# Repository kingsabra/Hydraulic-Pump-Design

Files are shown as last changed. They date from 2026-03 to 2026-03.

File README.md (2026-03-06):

# Hydraulic Pump Design — Bilge Pump

Mechanical design and assembly package for a **hand-crank / mechatronic bilge pump** (piston pump). Created for **U.S. Coast Guard Academy — Introduction to Mechanical Design (IMED), Spring 2022**, Team 4.

The pump can be built in two configurations: **manual crank drive** or **motorized drive** controlled by an Arduino and a water-level sensor.

---

## Repository structure

| Folder | Contents |
|---|---|
| **`cad/`** | All SolidWorks files: main assembly, pump parts, fasteners, and drawings. Open `cad/Assem1.SLDASM` in SolidWorks to view the full assembly. |
| **`docs/`** | Reports (assembly instructions, BOM, drawing exports) in PDF and DOCX. |
| **`media/`** | Renders and animations (e.g. mechanism animation). |
| **`misc/`** | Other artifacts (e.g. SolidWorks add-in logs); safe to ignore for normal use. |

---

## What’s in each folder

### `cad/`
- **`Assem1.SLDASM`** — Main pump assembly.
- **Parts (`.SLDPRT`)** — Pump body, piston, connecting rod, axle, crank disk, crank handle, handle, support arm, piston screw, quick-disconnect coupling (male).
- **`screws/`** — Fastener and fitting library (set screws, bolts, brass fitting, etc.) used in the assembly.
- **`IMED_MS_001.SLDDRW`** — Multi-sheet drawing (BOM and part/detail views).
- **`CGA B Landscape.slddrt`** — Drawing template (title block, border).

### `docs/`
- **Assembly Report Team 4** (`.pdf`, `.docx`) — Full assembly process: pump body, handle, and mechatronics wiring. Primary reference for building the pump.
- **assembly report - Moustafa Mahmoud Sabra** (`.pdf`, `.docx`) — Separate OIR/interview report (not pump assembly steps).
- **`IMED_MS_drawings.PDF`** — Exported drawing set (BOM, dimensions, tolerances).

### `media/`
- **`Animation1.mp4`** — Short animation of the pump mechanism.

### `misc/`
- **`console.log`** — SolidWorks Marketplace add-in log; not part of the design. You can add `misc/console.log` to `.gitignore` if you don’t want it in the repo.

---

## Main parts (from BOM)

Pump body, support arm, axle, crank disk, crank handle, handle, connecting rod, piston, piston screw, quick-disconnect coupling, plus standard hardware (set screws, bolts, NPT barbed fitting, ball bearings) as listed in the assembly report and `IMED_MS_drawings.PDF`.

---

## How to use this repo

1. **View the assembly** — Open **SolidWorks** and open `cad/Assem1.SLDASM`. Keep all files under `cad/` (and `cad/screws/`) in place so references don’t break.
2. **Build the pump** — Follow **`docs/Assembly Report Team 4.pdf`** for step-by-step assembly (manual and mechatronics).
3. **Drawings and BOM** — Use **`docs/IMED_MS_drawings.PDF`** for dimensions and part list, or open `cad/IMED_MS_001.SLDDRW` in SolidWorks.

---

## Note on Arduino / firmware

The assembly report describes an **Arduino-based circuit** (C code in Arduino IDE) for motor control and water-level sensing. That **firmware is not included** in this repository; this repo contains only CAD and documentation. If you have the original sketch, you can add it in a folder such as `firmware/` and reference it in this README.

---

## License and use

SolidWorks files are marked as **Educational Product**. Use according to your institution’s and SolidWorks’ terms. Reports and drawings are from the referenced course and authors.

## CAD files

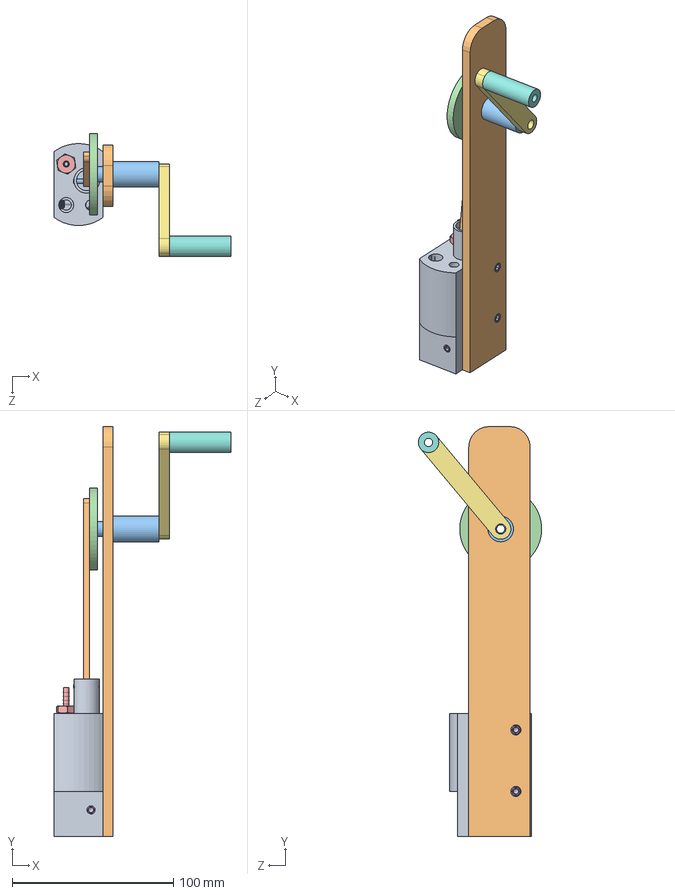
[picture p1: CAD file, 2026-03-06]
cad/Assem1.SLDASM
109.5 x 254.0 x 76.4 mm
Pump Body
Support Arm
Pump Axie
Pump Crank Disk
5454K650_MINIATURE BRASS FITTING
92158A417_Super-Corrosion-Resistant Flat-Tip Set Screws x 6
Pump Crank Handle
Pump Handle
Pump Piston
Pump Connecting Rod
piston screw

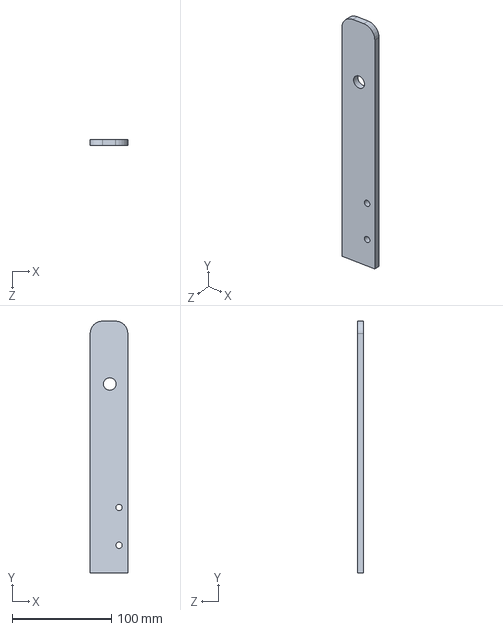
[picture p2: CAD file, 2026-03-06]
cad/Support Arm.SLDPRT
38.1 x 254.0 x 6.35 mm

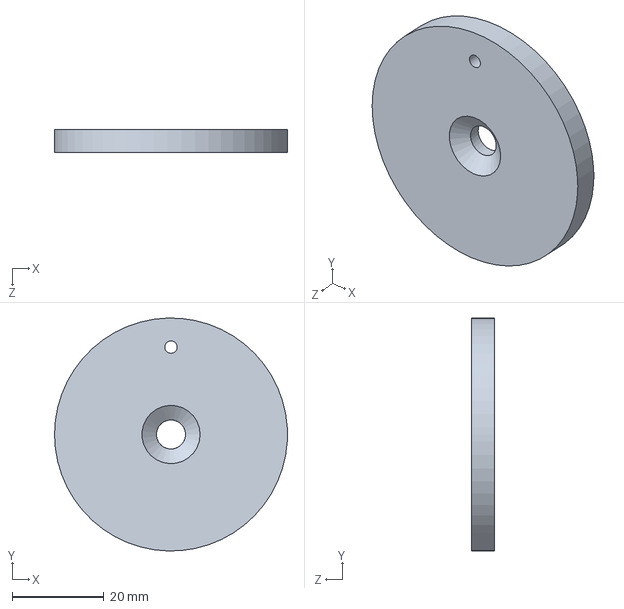
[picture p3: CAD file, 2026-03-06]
cad/Pump Crank Disk.SLDPRT
50.8 x 50.8 x 5.08 mm

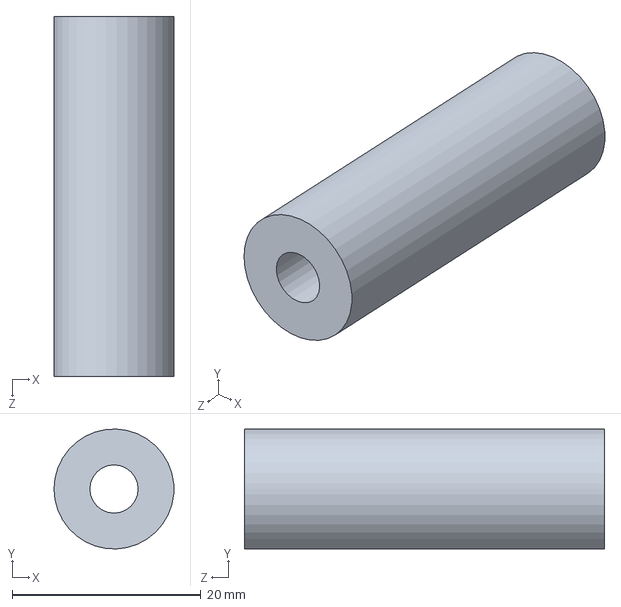
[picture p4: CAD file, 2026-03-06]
cad/Pump Handle.SLDPRT
12.7 x 12.7 x 38.1 mm

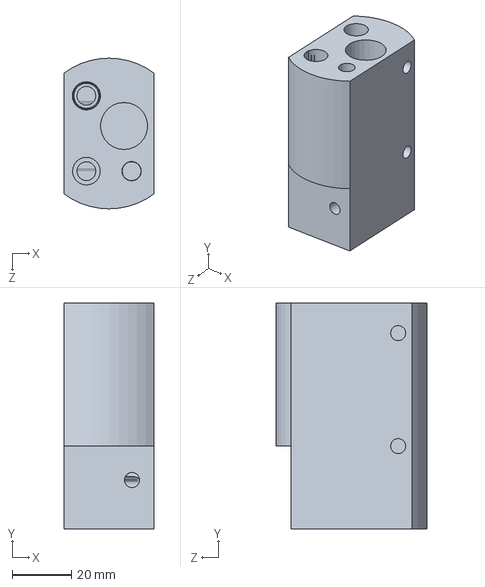
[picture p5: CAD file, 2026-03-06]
cad/Pump Body.SLDPRT
30.2 x 76.2 x 50.8 mm

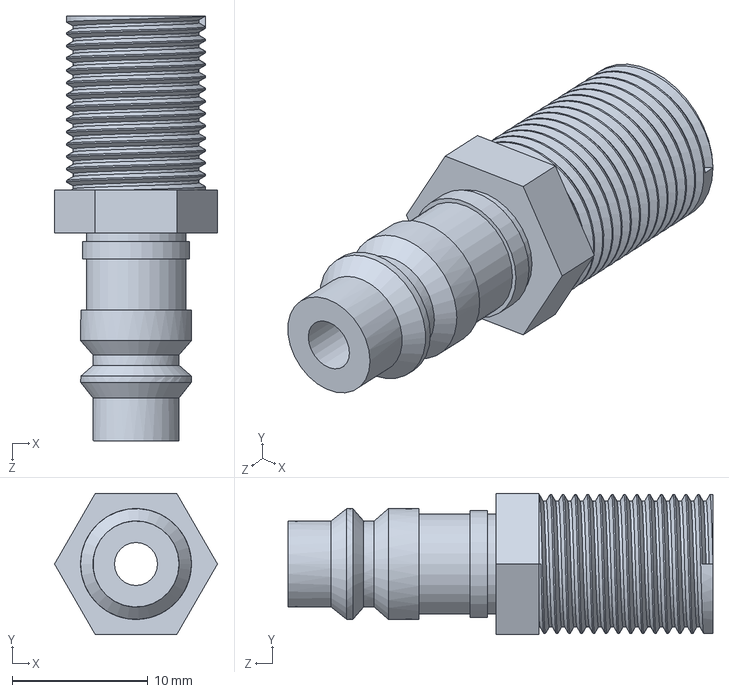
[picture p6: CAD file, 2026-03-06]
cad/quick disconnect coupling male.SLDPRT
12.0 x 10.4 x 31.4 mm

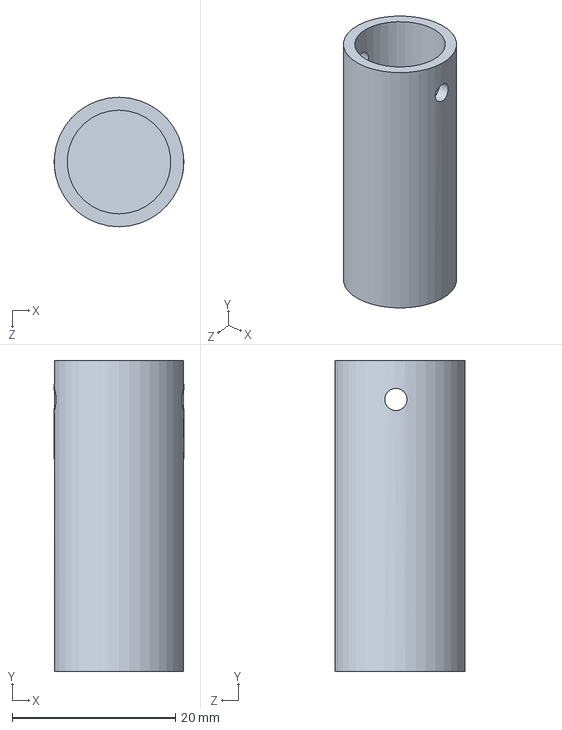
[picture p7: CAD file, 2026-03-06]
cad/Pump Piston.SLDPRT
15.9 x 38.1 x 15.9 mm

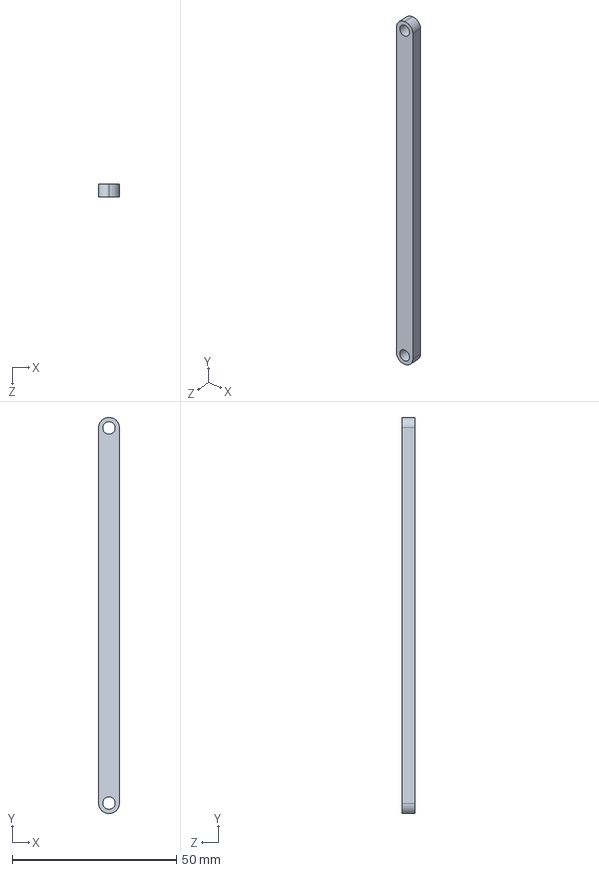
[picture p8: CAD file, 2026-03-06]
cad/Pump Connecting Rod.SLDPRT
6.35 x 120.7 x 3.81 mm

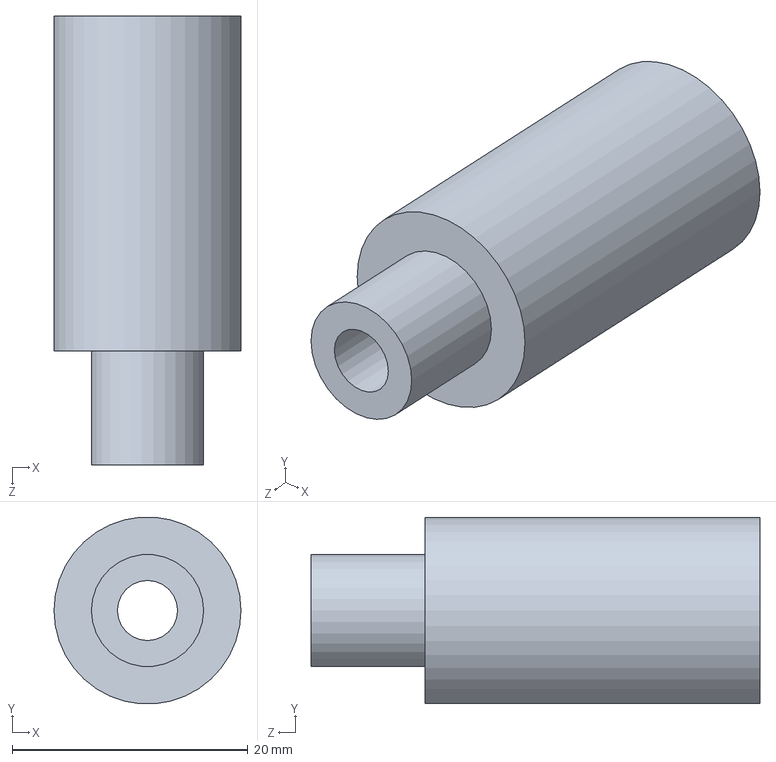
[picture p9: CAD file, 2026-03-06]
cad/Pump Axie.SLDPRT
15.9 x 15.8 x 38.1 mm

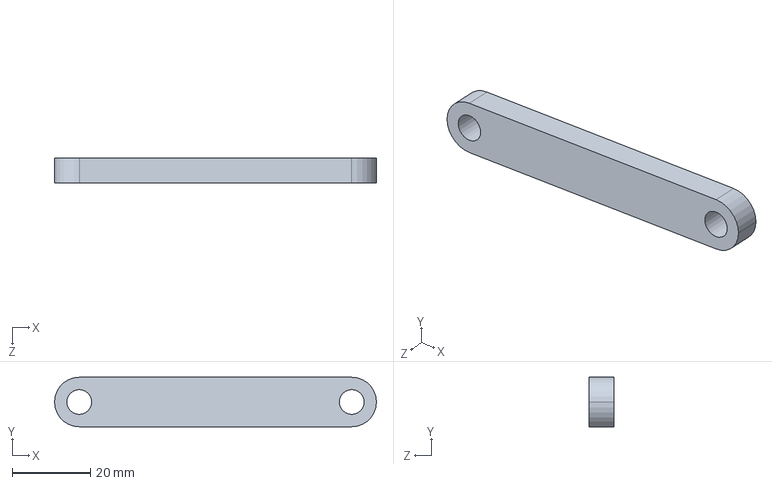
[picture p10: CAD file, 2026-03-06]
cad/Pump Crank Handle.SLDPRT
82.5 x 12.7 x 6.35 mm

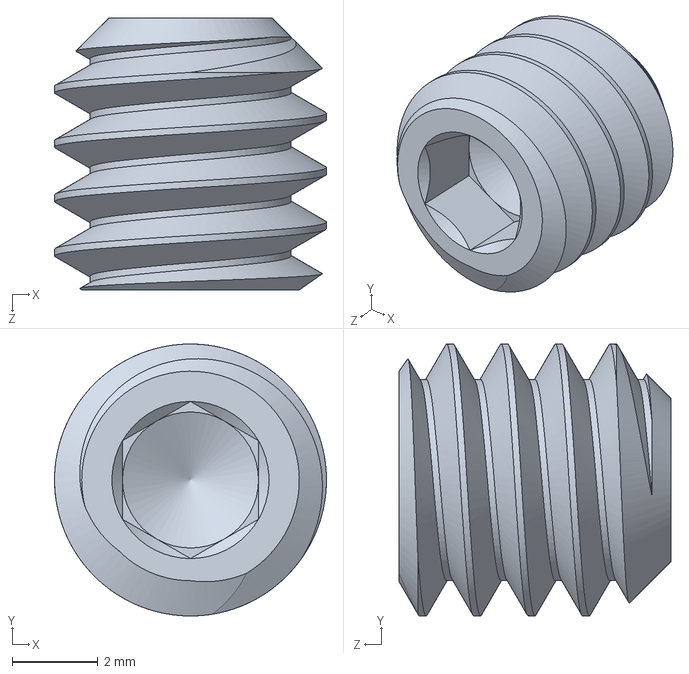
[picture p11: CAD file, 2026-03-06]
cad/screws/92158A417_Super-Corrosion-Resistant Flat-Tip Set Screws.SLDPRT
6.35 x 6.35 x 6.35 mm

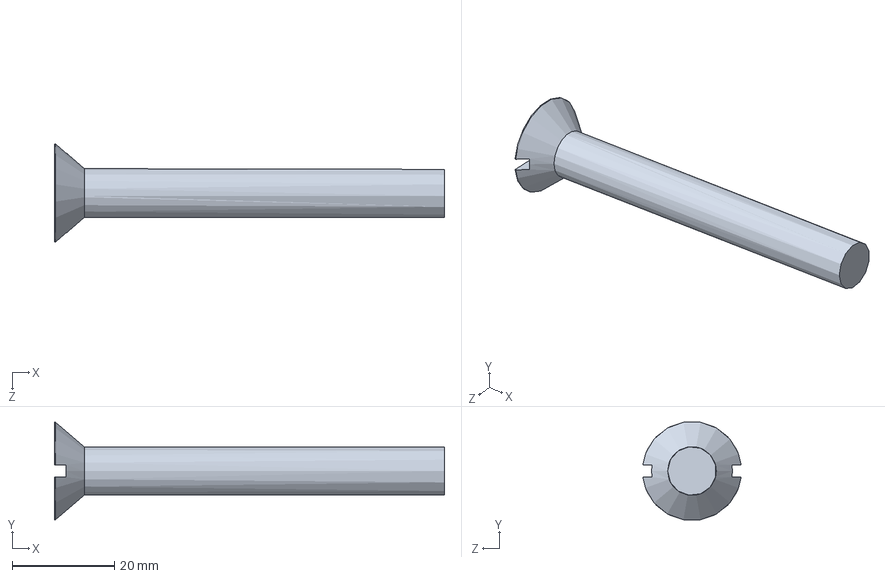
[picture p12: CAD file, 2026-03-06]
cad/screws/CSBOLT 0.2500-20x0.75x0.75-S-N.sldprt
76.2 x 19.1 x 19.2 mm

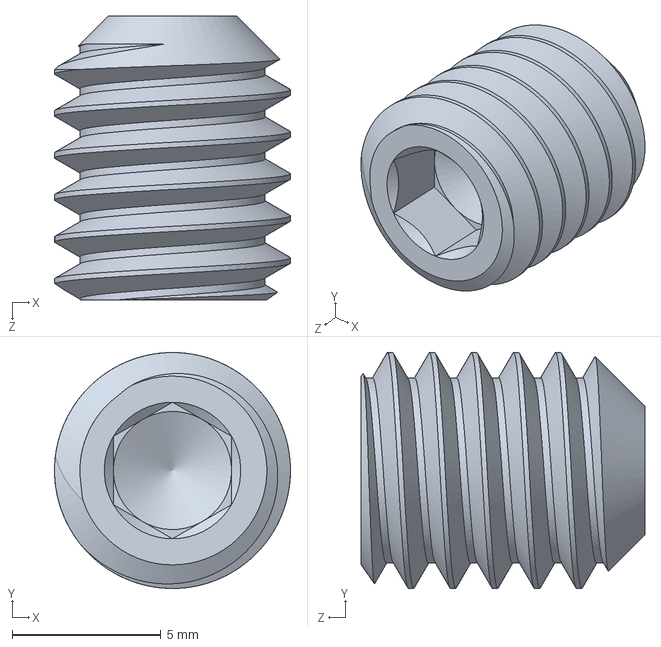
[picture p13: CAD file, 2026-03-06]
cad/screws/92311A576_18-8 Stainless Steel Cup-Point Set Screw.SLDPRT
7.92 x 7.92 x 9.52 mm

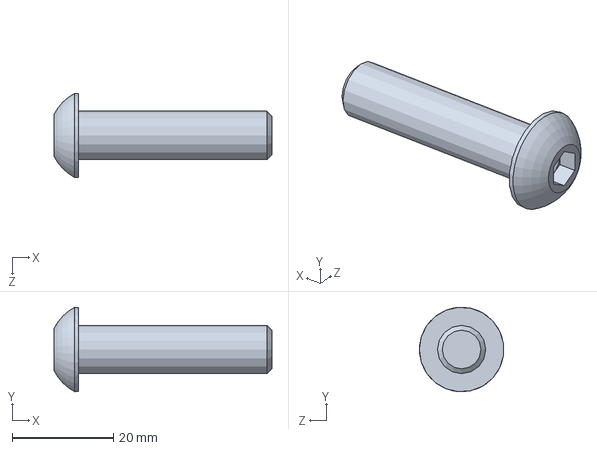
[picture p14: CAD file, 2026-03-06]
cad/screws/SBHCSCREW 0.138-32x0.375-HX-N.sldprt
43.0 x 16.7 x 16.6 mm

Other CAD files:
cad/piston screw.SLDPRT
cad/screws/5454K650_MINIATURE BRASS FITTING.SLDPRT
cad/screws/SBHCSCREW 0.125-40x0.375-HX-N.sldprt
cad/screws/CSBOLT 0.2500-20x0.5x0.5-S-N.sldprt
cad/IMED_MS_001.SLDDRW
cad/screws/92311A937_18-8 Stainless Steel Cup-Point Set Screw.SLDPRT
cad/screws/CSBOLT 0.2500-20x0.75x0.75-S-C.sldprt
cad/screws/HBOLT 0.2500-20x0.5x0.5-N.sldprt

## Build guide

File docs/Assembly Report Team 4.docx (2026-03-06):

Report No: 4001

U.S Coast Guard Academy

Introduction to Mechanical Design (1208)

2022

Team 4: Bilge Pump

Bilge Pump

Author: Moustafa Mahmoud Sabra ________________________

Checked: 3/c Kevin Hall ________________________

Issue Date: 04/27/2022

Electronic Folder: IMED Spring 2022\Documents\General\Lab Material

# Abstract

Assembling the bilge pump requires minimal tools or experience and can be completed by splitting the pump into a few fundamental pieces. The assembly processes can be broken into the pump body assembly, the handle assembly, the mechatronics circuit assembly, and eventually the final product assembly. The exact steps are detailed in this report.

# Acknowledgment

It is essential to acknowledge that the completion of the prototype would not have been possible without the supervision of CDR Ryan Angelo and Dr. Richard Freeman. In addition, a special thanks should be issued to the managing staff of the United States Coast Guard Academy Power Lab for their contributions toward the fabrication and assembly of the pump body parts and final product.

# Chapter 1: Introduction

The parts manufactured using machines in the Power Lab include the pump body, support arm, axle, connecting rod, crank arm, crank disc, piston, and handle.

Additional parts were used to enable the mechanics and connections between the main parts mentioned previously, containing the NPT barbed fitting, ball bearings, and set screws with appropriate sizes that match the design parameters.

An Arduino-based circuit was constructed to control the rotation of the pump motor and piston. An EGLEGOO Mega R3, Arduino Motor Shield, motor driver, breadboard, power supply, jumpers, and water level sensor were used to construct the monitoring circuit.

The final prototype comes with two configurations, either a manual-based drive or a mechatronic-based drive. The manual drive relies on the user exerting force manually to turn the crank disk, while the mechatronic-based version utilizes a DC motor for rotating the crank disk.

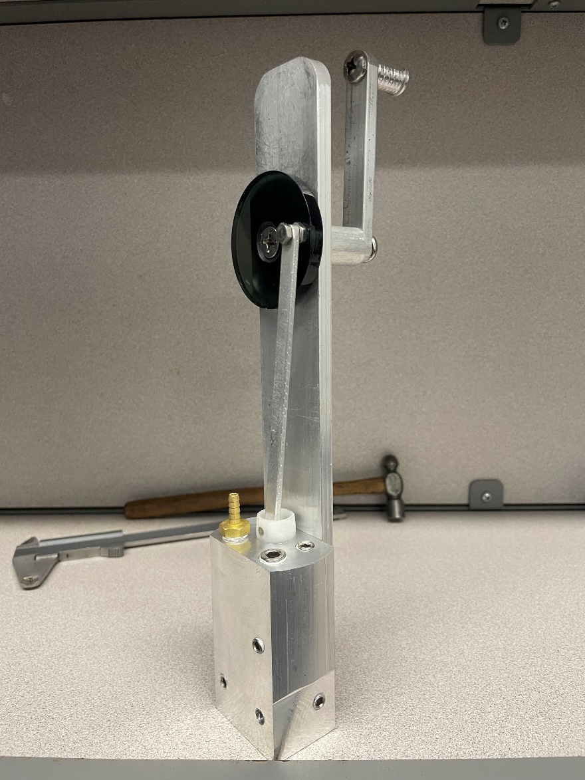
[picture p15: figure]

Support Arm

1/8 NPT Barbed Fitting

5/16 inch Set Screw

7/16 inch Set Screw

Piston

1/4 inch Set Screw

1/4 inch Set Screw

Axel

Crank Rod

Handle

Pump Body

Connecting Rod

Crank Disc

Figure 1 Assembled pump with hand crank

The project’s parts are labeled in Figure 1 above and the final prototype is shown in Figure 2.

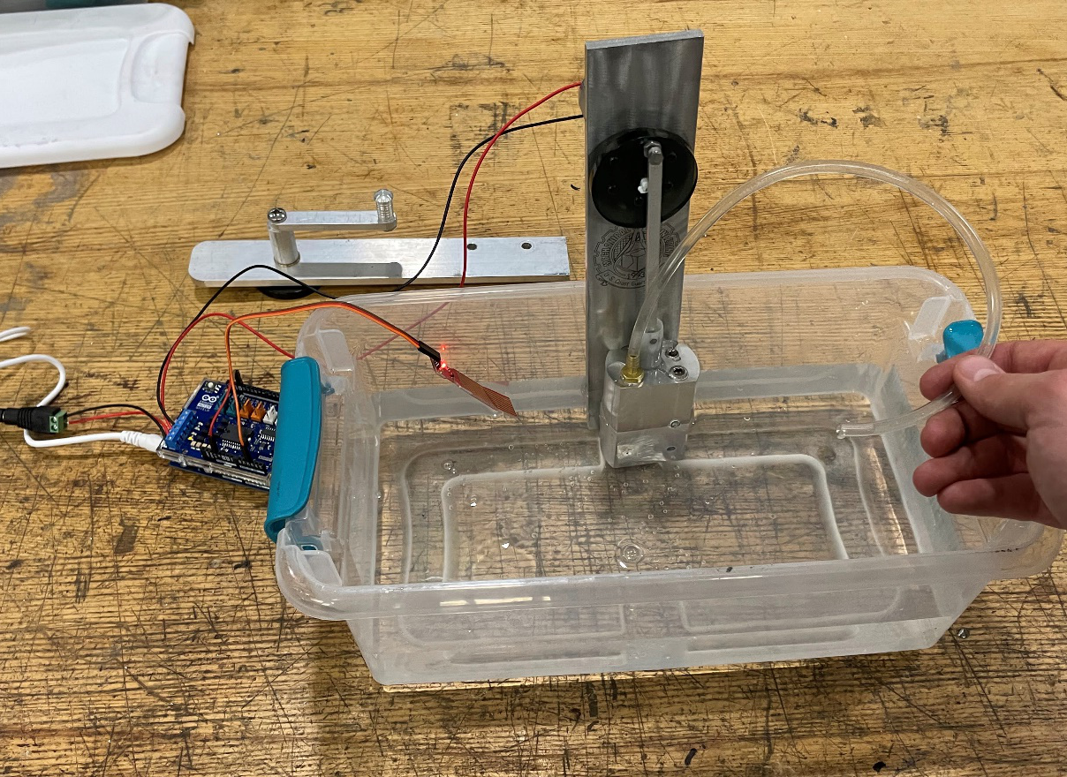
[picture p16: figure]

Figure 2 Assembled pump with motor and Arduino

The following general procedure was used to build both prototypes:

Manual-based mechanical drive

1. Screw the pump body to the front side of the support arm
2. Attach the handle piece to the backside of the support arm
3. Place the crank disk on the front side of the handle
4. Screw the disk to the handle
5. Connect the connecting rod to the piston
6. Screw the connecting rod to the crank disk

Mechatronics-based drive more

1. Screw the pump body to motor support arm
2. Align the DC motor in the top center hole of the backplate
3. Screw the DC motor to the support arm
4. Attach the crank disk to the motors shaft
5. Connect the connecting rod to the piston
6. Screw the connecting rod to the crank disk
7. Connect the DC motor to the Arduino circuit

# Chapter 2: Assembly of Each Section

## 2.1 The Pump Body Assembly

Figure 3 below shows the configuration of the pump body, barbed fitting, and set screws. One 5/16 ball bearing was placed inside the holes beneath the barbed fitting and 7/16 inch set screw. The barbed fitting was screwed to its assigned location on the lower left hole on the body’s top side. Five set screws fitted with Teflon tape were then placed to cover all of the holes besides the intake in the front side of the body.

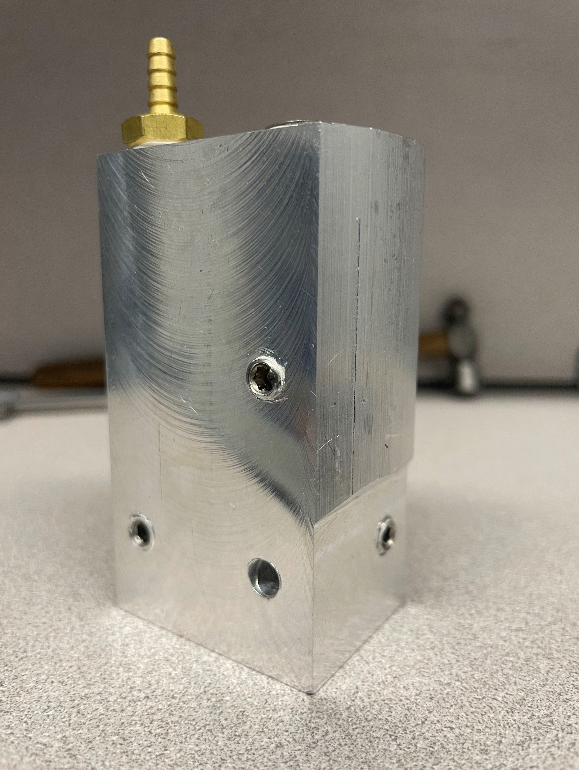
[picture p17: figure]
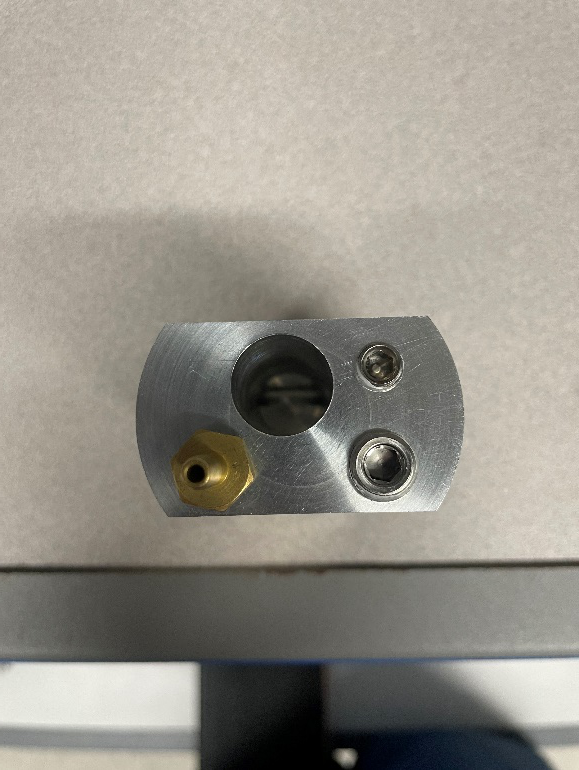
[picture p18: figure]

Figure 3 Top and side views of the pump body

## 2.2 The Pump Manual Handle Assembly:

The handle piece was designed to give the user a means to exert mechanical force to rotate the crank disk. Figure 4 shows the final version of the handle connected to the supporting arm. After the pump body is connected to the backplate, the axle is positioned in the top hole of the backplate. On the side holding the pump body, the crank disk is fitted to the smaller end of the axle. On the other side, the crank arm is connected to the back of the axle. Finally, the handle cylindrical piece is screwed to the other end of the crank rod.

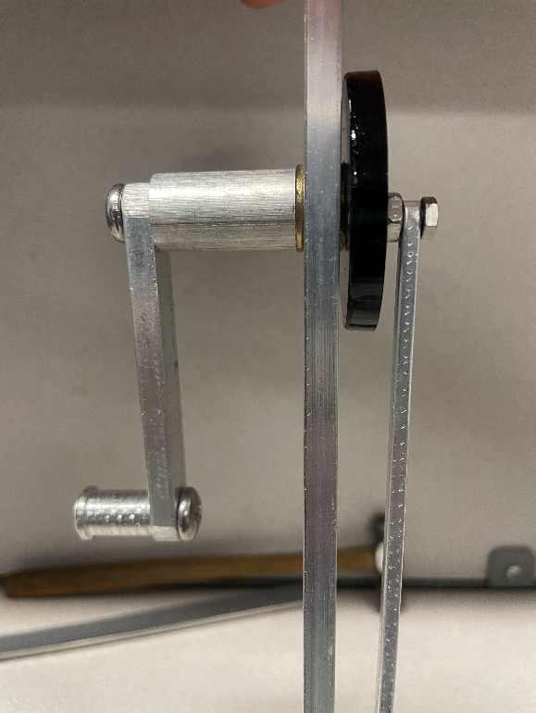
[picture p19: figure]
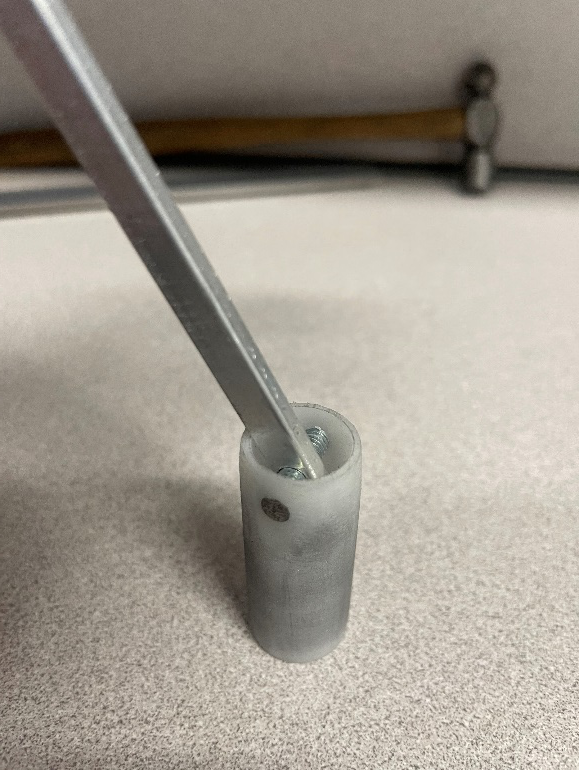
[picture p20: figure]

Figure 4 Crank and Connecting Rod assembly

## 2.3 The Mechatronics circuit:

A simple Arduino circuit was designed to automate the pump based on the presence of water. Jumpers, an Arduino board, a water-level sensor, and a motor shield were the main components of the circuit. The motor shield is attached to the EGLEGOO board in the assigned power and ground pins as shown in Figure 5. A pair of jumpers extends from the Motor Shield terminals to the power and ground connections of the DC motor and power supply as shown in Figure 6. The liquid-level sensor is connected to the Arduino pins GND, A2, and 3.3V to activate the pulse width modulation script loaded on the Arduino board to read and interpret water-level measurements. The water level sensor is then programmed using the Arduino IDE in C to activate the pump once the water level is below a certain threshold. Eventually, the power supply is connected to the Motor Shield’s power and ground pins using a pair of jumpers to supply the circuit with 12 V. The shield will make sure to only supply the other parts of the circuit their capacity with no additional load, allowing an even distribution of power through the circuit. Since the DC motor needs more power, it takes 12 V from the shield while only a maximum of 5 V is supplied from or to the Arduino board.

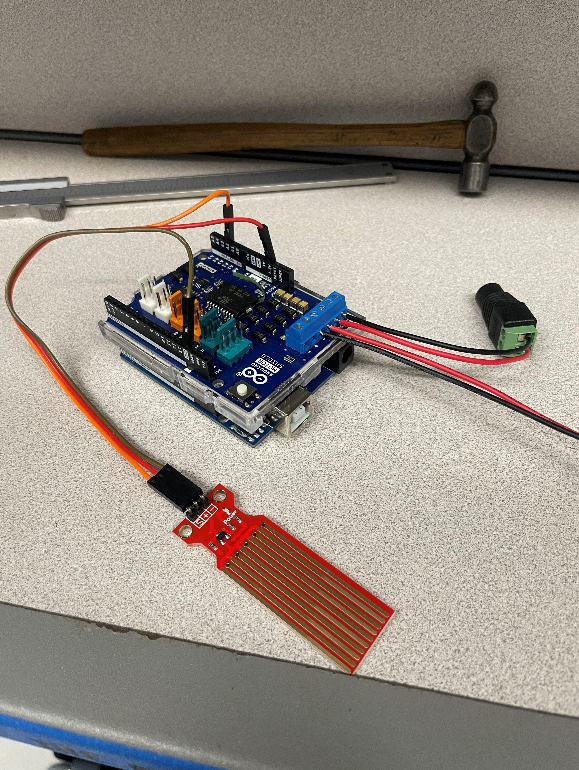
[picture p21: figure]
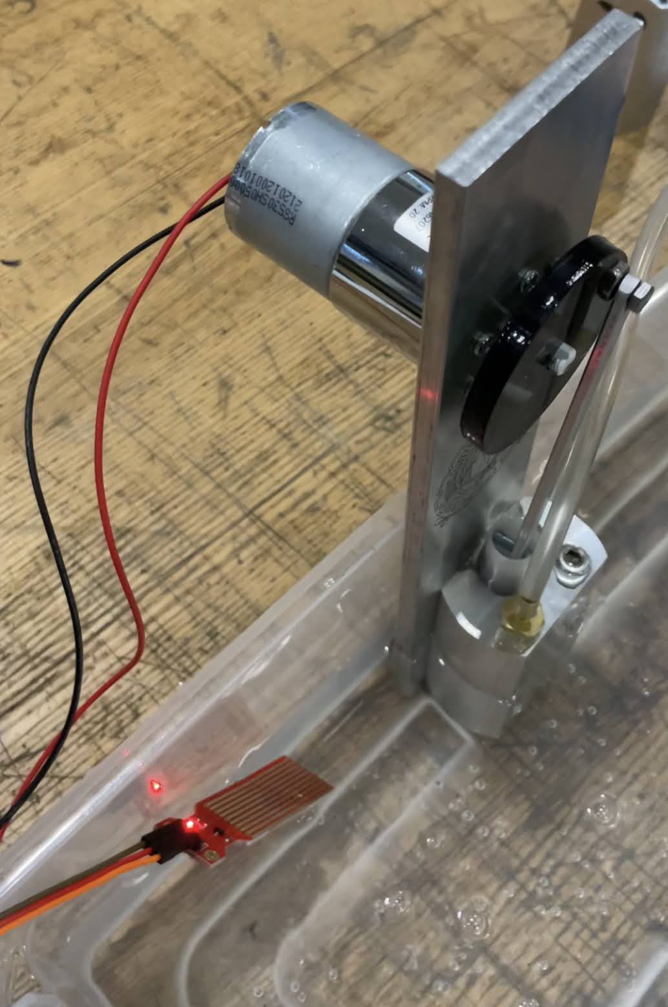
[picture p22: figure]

Figure 5 Arduino wiring and motor attachment

# Chapter 3: Recommendations and conclusions:

Many changes to the design of the bump body could be applied if it were re-built. Various assembly issues were faced such as accurately estimating the amount of material to sand off of the piston sides to achieve the required suction. Additional issues arise when implementing the mechatronics-based drive mode, as it is usually hard to fit the Arduino in a place where its motion doesn’t interfere with the motor or the water level sensor

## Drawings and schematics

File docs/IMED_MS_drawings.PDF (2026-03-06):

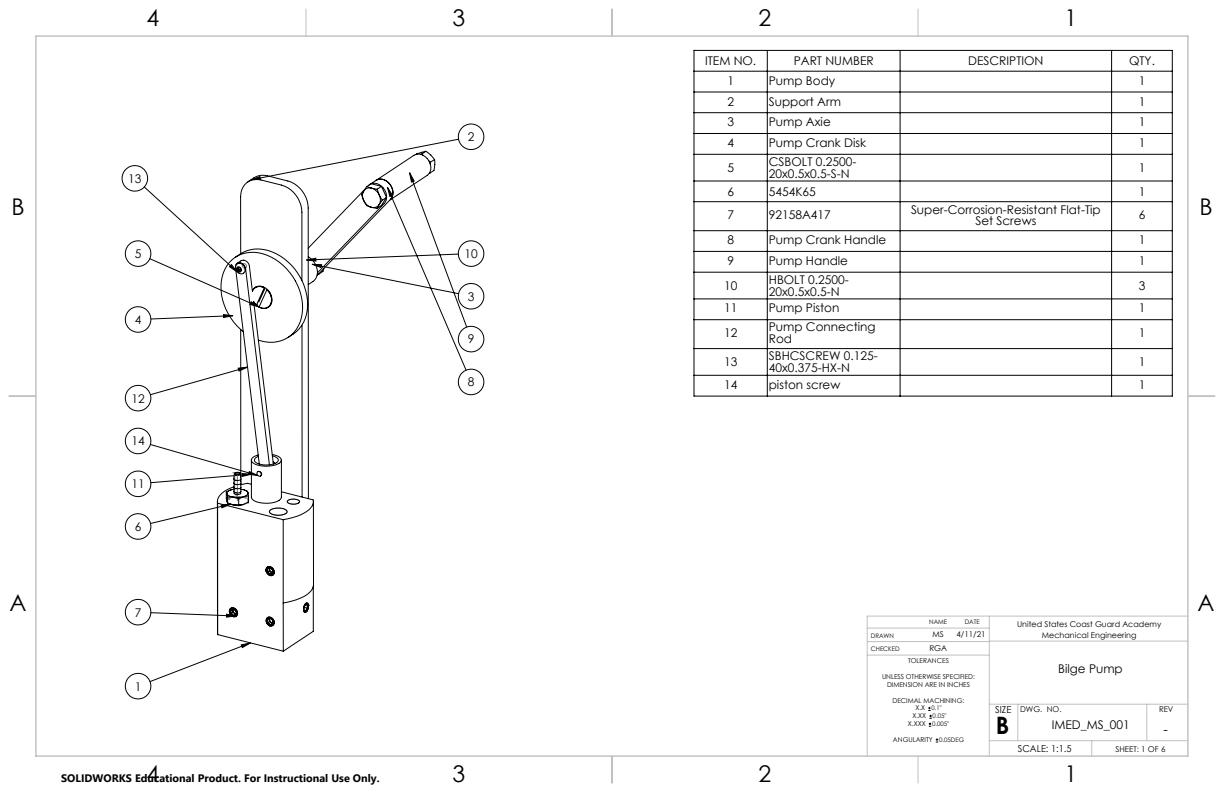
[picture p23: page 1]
Bilge Pump; DRAWN; Mechanical Engineering

ITEM NO. | PART NUMBER | DESCRIPTION | QTY.
1 | Pump Body | | 1
2 | Support Arm | | 1
3 | Pump Axie | | 1
4 | Pump Crank Disk | | 1
5 | CSBOLT 0.2500-20x0.5x0.5-S-N | | 1
6 | 5454K65 | | 1
7 | 92158A417 | Super-Corrosion-Resistant Flat-Tip Set Screws | 6
8 | Pump Crank Handle | | 1
9 | Pump Handle | | 1
10 | HBOLT 0.2500-20x0.5x0.5-N | | 3
11 | Pump Piston | | 1
12 | Pump Connecting Rod | | 1
13 | SBHCSCREW 0.125-40x0.375-HX-N | | 1
14 | piston screw | | 1

RGA
TOLERANCES
UNLESS OTHERWISE SPECIFIED:
DIMENSION ARE IN INCHES
DECIMAL MACHINING:
X.XXX 0.005"
ANGULARITY 0.05DEG

United States Coast Guard Academy

SIZE B | DWG. NO. IMED_MS_001 | REV -

SCALE: 1:1.5 | SHEET: 1 OF 6

SOLIDWORKS Educational Product. For Instructional Use Only.

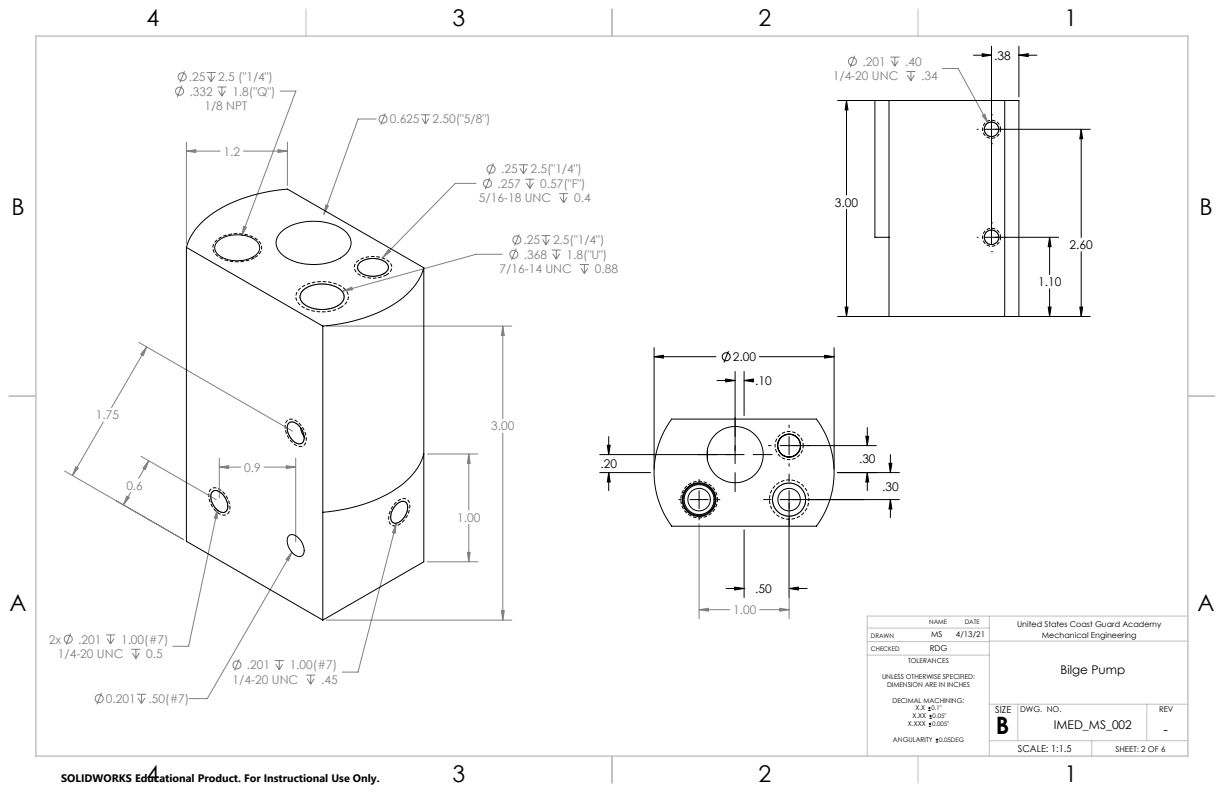
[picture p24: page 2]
Bilge Pump; 1/4-20 UNC; 5/16-18 UNC; .25 2.5 ("1/4") .332 1.8("Q") 1/8 NPT; 7/16-14 UNC; DRAWN; Mechanical Engineering; DWG. NO.; REV; X.XX 0.05" X.XXX 0.005"

RDG
TOLERANCES
UNLESS OTHERWISE SPECIFIED:
DIMENSION ARE IN INCHES
DECIMAL MACHINING:

United States Coast Guard Academy

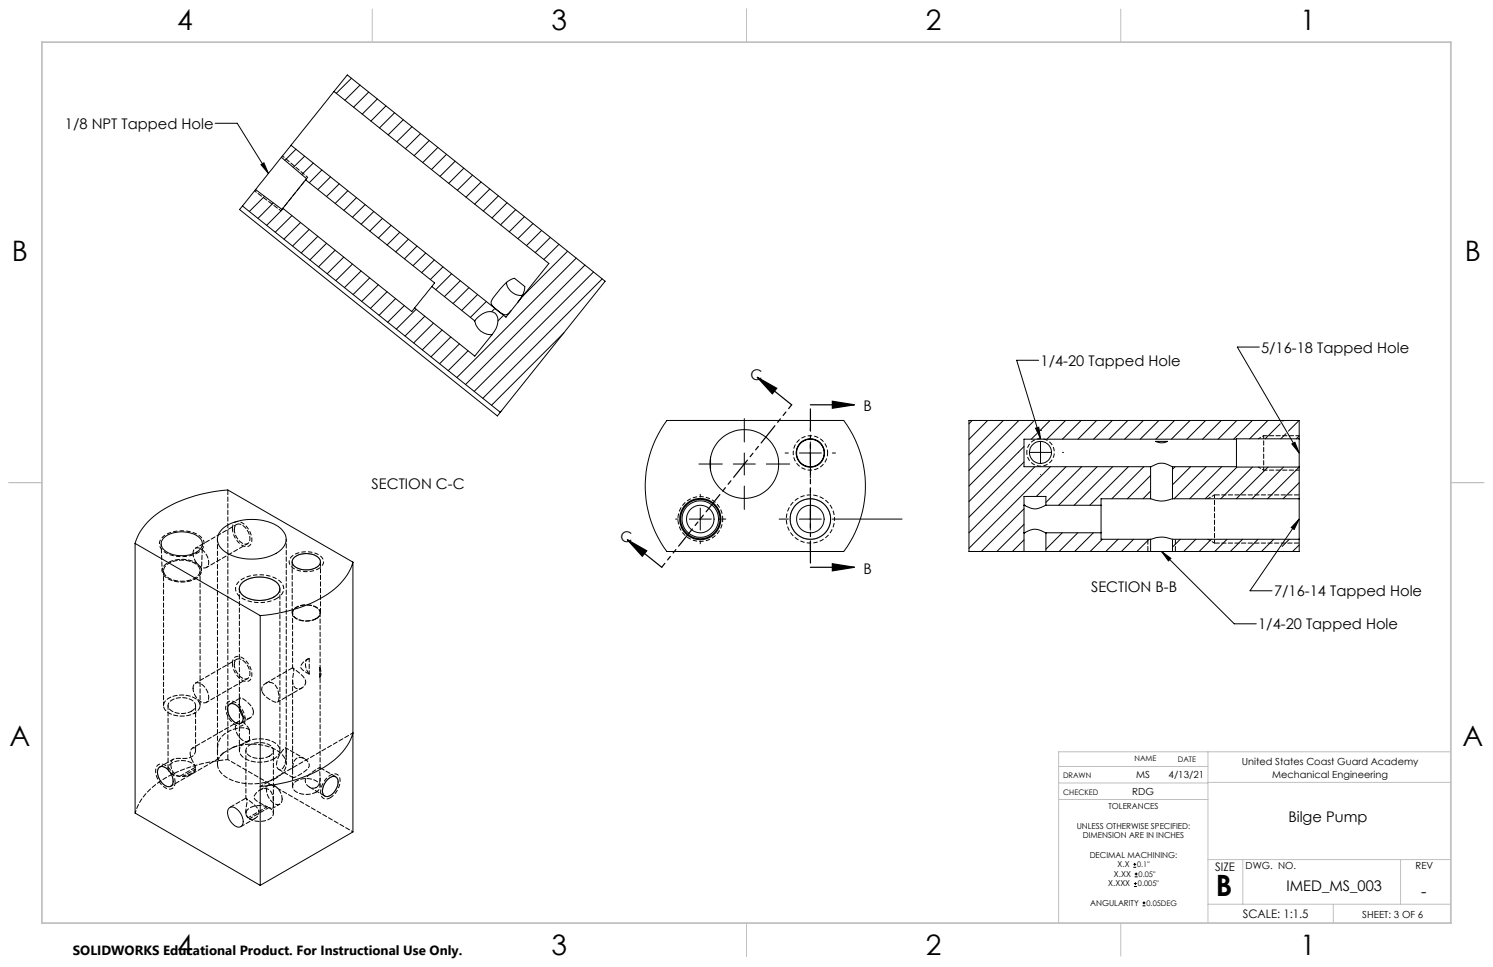
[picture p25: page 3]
Bilge Pump; 7/16-14 Tapped Hole; 5/16-18 Tapped Hole; 1/4-20 Tapped Hole; SECTION B-B; SECTION C-C; DRAWN; Mechanical Engineering; DWG. NO.; REV; X.XX 0.05" X.XXX 0.005"

1/8 NPT Tapped Hole

RDG
TOLERANCES
UNLESS OTHERWISE SPECIFIED:
DIMENSION ARE IN INCHES
DECIMAL MACHINING:

United States Coast Guard Academy

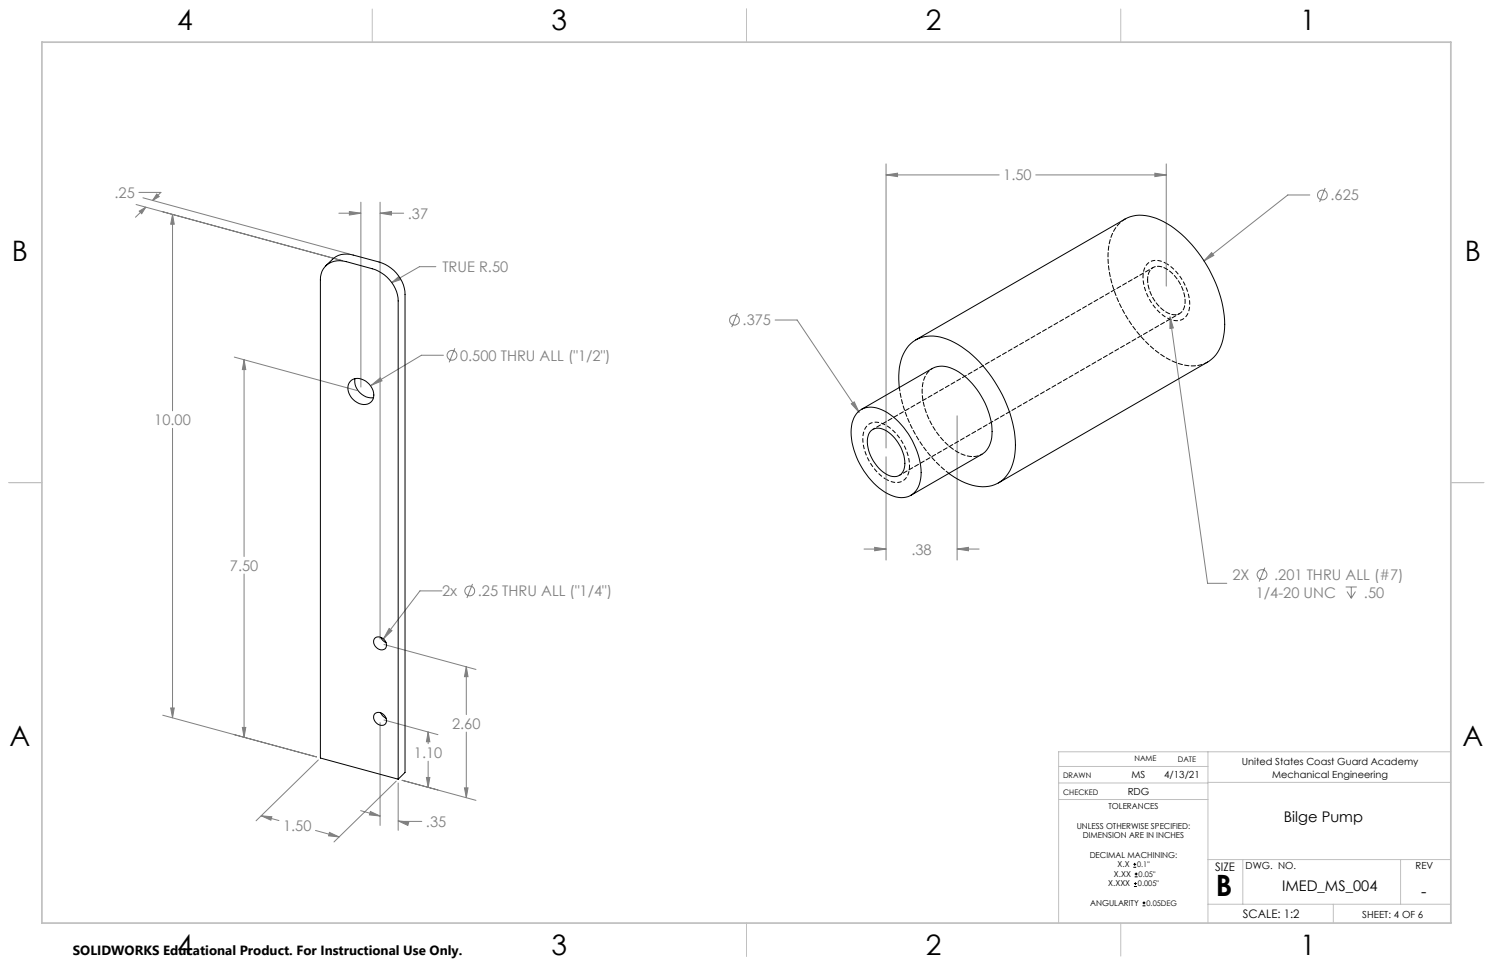
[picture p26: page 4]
TRUE R.50; 0.500 THRU ALL ("1/2"); 2x .25 THRU ALL ("1/4"); .201 THRU ALL (#7); 1/4-20 UNC; Bilge Pump; DRAWN; Mechanical Engineering

RDG
TOLERANCES
UNLESS OTHERWISE SPECIFIED:
DIMENSION ARE IN INCHES
DECIMAL MACHINING:
X.XXX 0.005"

United States Coast Guard Academy

SIZE B | DWG. NO. IMED_MS_004 | REV -

SCALE: 1:2

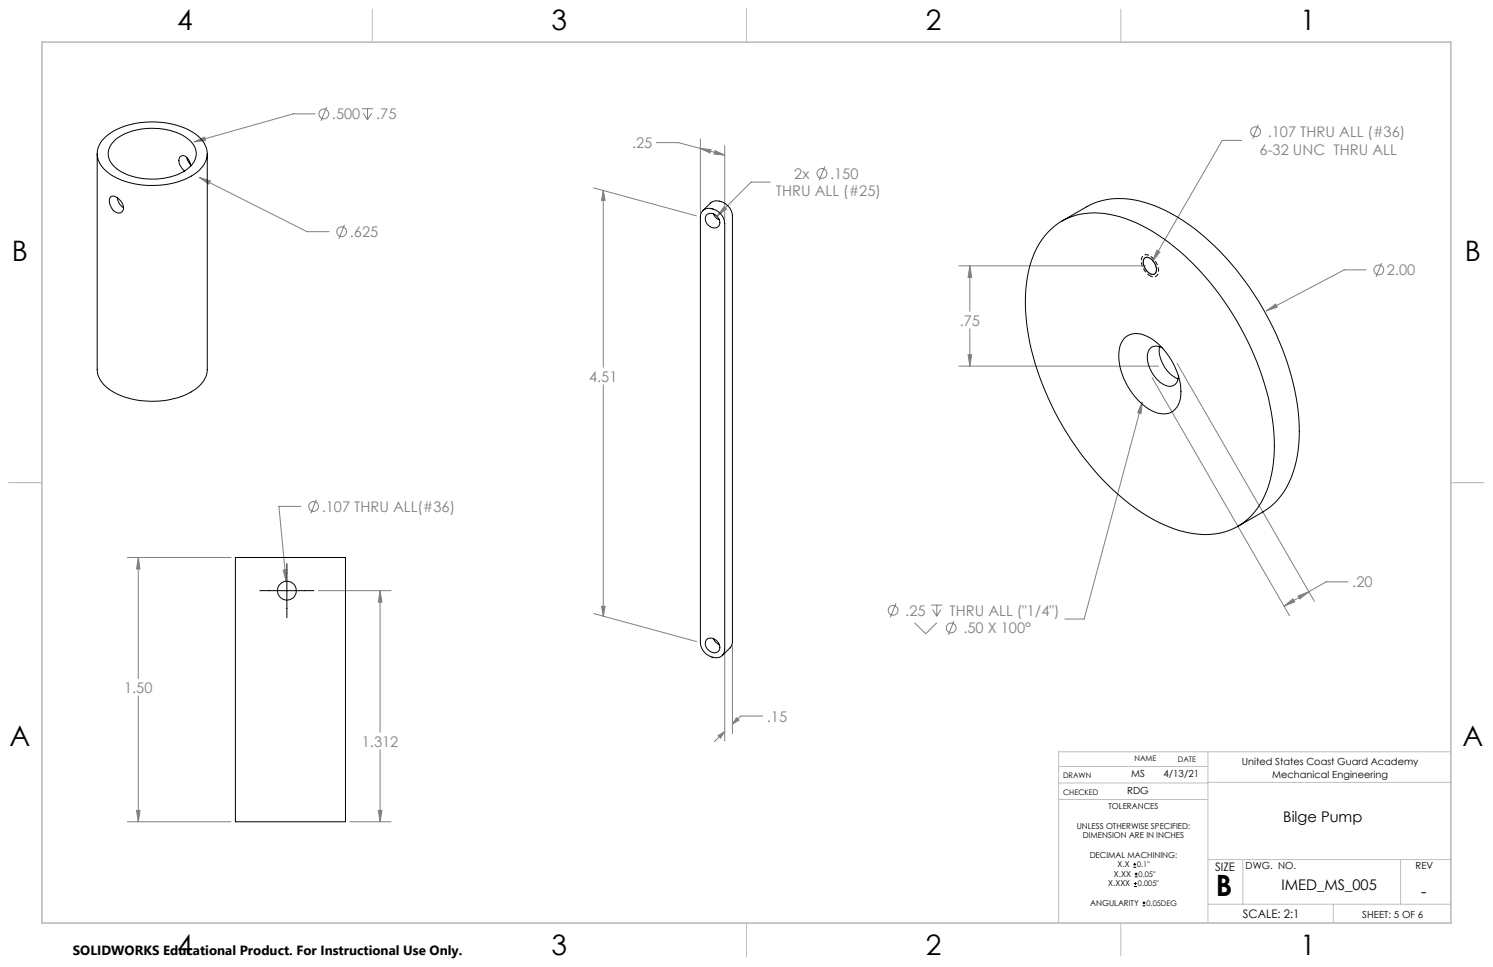
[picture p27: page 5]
.107 THRU ALL(#36); 2x .150 THRU ALL (#25); .25 THRU ALL ("1/4") .50 X 100°; Bilge Pump; DRAWN; Mechanical Engineering; UNLESS OTHERWISE SPECIFIED: DIMENSION ARE IN INCHES; DECIMAL MACHINING: X.X 0.1" X.XX 0.05" X.XXX 0.005"

.107 THRU ALL (#36)
6-32 UNC THRU ALL

United States Coast Guard Academy

SIZE B | DWG. NO. IMED_MS_005 | REV -

SCALE: 2:1

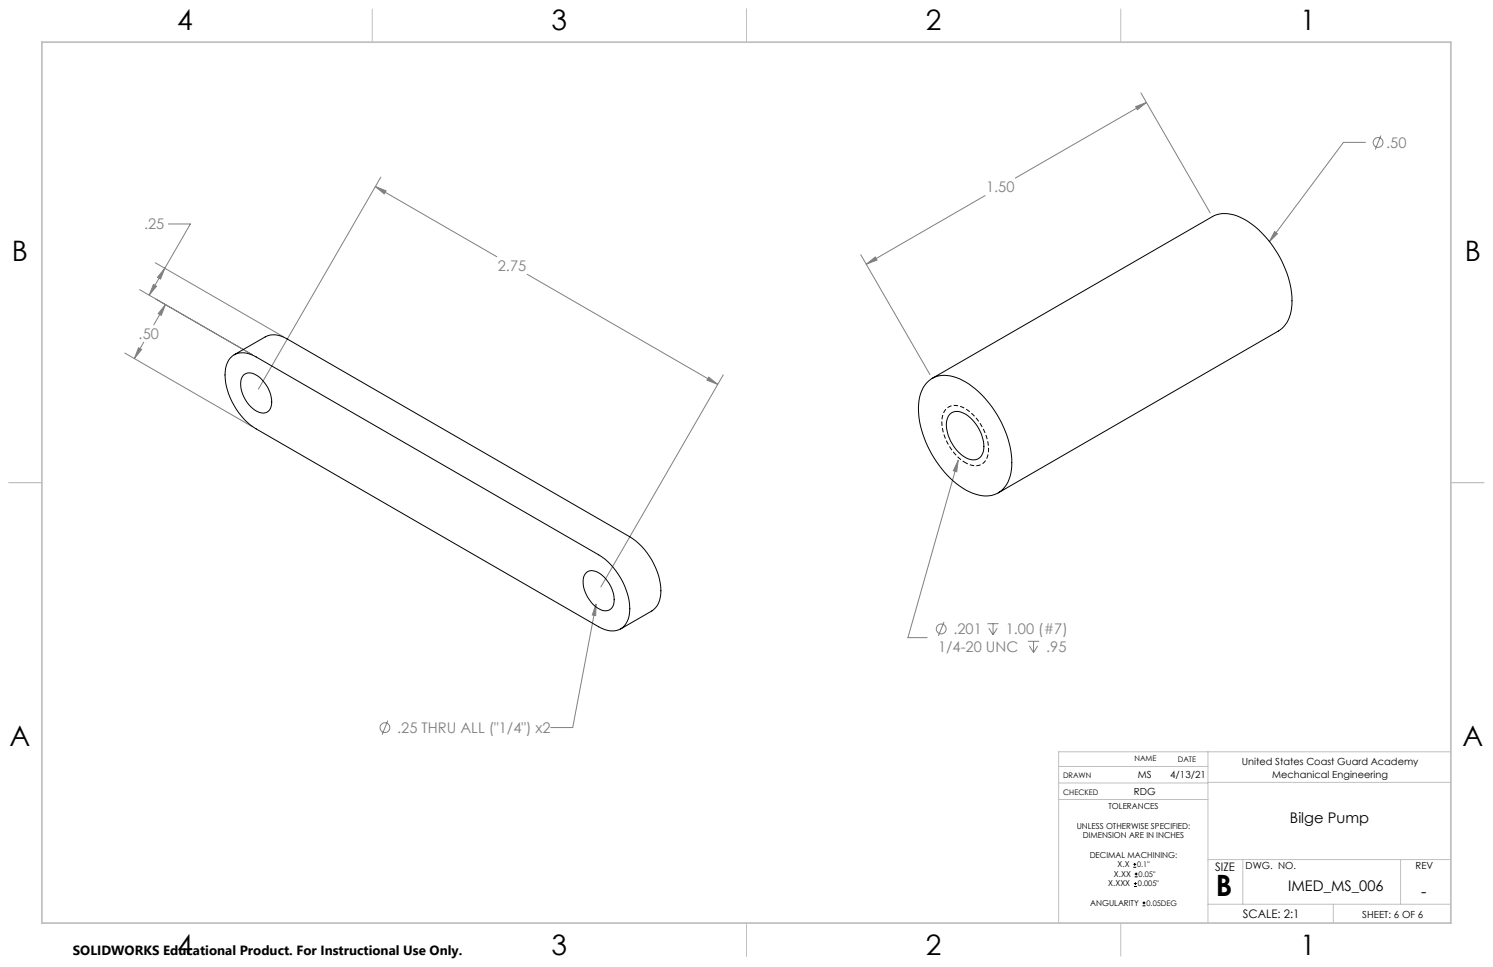
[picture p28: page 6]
.25 THRU ALL ("1/4") x2; 1/4-20 UNC; Bilge Pump; DRAWN; Mechanical Engineering

RDG
TOLERANCES
UNLESS OTHERWISE SPECIFIED:
DIMENSION ARE IN INCHES
DECIMAL MACHINING:
X.XXX 0.005"

United States Coast Guard Academy

SIZE B | DWG. NO. IMED_MS_006 | REV -

SCALE: 2:1
